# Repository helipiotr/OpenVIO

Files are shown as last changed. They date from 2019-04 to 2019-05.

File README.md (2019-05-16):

# OpenVIO - Open visual-inertial navigation hardware

OpenVIO is an open-source hardware project which aims to allow anyone to collect precisely synchronised visual and inertial data. It has been engineered due to the fact that the existing hardware is either too expensive or hard to get, barring anyone interested in this discipline from accesing the raw data. Despite its simplicity and design quirks, it is theoretically able to achieve accuracy and performance on par with the existing VIO solutions. Contributions and issues are welcome.

# Brief description
The system is composed of the following sub-systems:
- Raspberry Pi (version higher than 3) - collects the visual data via the PiCamera. Also, it generates the frame synchronization pulses [RPi_frame_sync](https://www.raspberrypi.org/forums/viewtopic.php?t=190314) by altering the configuration blob so that the Broadcom SoC pins are connected directly to the header.
- An expansion board featuring a STM32 microcontroller, that also has ADXL355 chip and BMG160 gyroscope. Its purpurse is to collect the inertial data in real time and send it Raspberry Pi in lax timing constraints. Alternatively, it can be used as an INS (inertial navigation system) that receives the pose corrections from the Raspberry Pi.
- A camera connected to the Raspberry Pi

The example software that was written with an intent to capture the raw data is included. It consists of camera sensor data mode on the microcontroller side and a program to read and store binary blobs that are being sent from the microcontroller. They can be analised using e.g. octave, python, or any other preferred language, but must be parsed to keep the data types first. Main features:
- Reading sensors in specified interval
- Possible synchronization of the sensor reading times with the image capture intervals
- Versatile sensor configuration
- High performance ADXL355 acceleration sensor (drivers ready)
- BMG160 gyroscope (drivers ready)
- DPS310 barometer
- BMA150 magnetometer

# Getting the hardware
It is possible to either use the attached Altium Designer files or use the generated Gerber files, depending on the preference. If some of the BOM are not easily accessible, please report this in issues and I'll consider replacing the component. Even better, consider contributing to the repository. 

# Programming and development
Before any programming, it is required to re-configure the pinout of the Raspberry Pi as described in [RPi_frame_sync](https://www.raspberrypi.org/forums/viewtopic.php?t=190314). Only after that RPi can be used with the sensor expansion board. GPU memory increase for the camera might be required for capturing the full sensor resolution, this can be done by changing a line in a configuration file.

Regarding the software embedded in STM32, AC6 development software is preffered to be used with the existing project. The microcontroller can be programmed using any STM32F4 compatible programmer. 

# Known issues
- The time synchronization is a bit off, this should be like 1ms but is actually closer to 0.991ms. Likely a timer issue.
- The DMA that is being used for the communication between Raspberry Pi and STM32 is failing quite routinely. Maybe a change in protocol / communication paradigm (DMA timeouts?) will bring this to an end.
- As DMA quite routinely fails, this messes up the timing data completely. Please don't be surprised if the saved binary blob contains nonsense, very often acceleration / angular velocity data is just fine with timing being just garbage.
- Gyroscope in hardware version 1.2 is not yet supported, but the library can be easily added from the Bosch Sensortronic website. 

# License
All hardware must not be used for any activity other than academic or educational due to the licensing. Software that contains a copyright notice from Bosch Sensortec GmbH has to be distributed within the limits of this license. All other components are subject to the MIT license.

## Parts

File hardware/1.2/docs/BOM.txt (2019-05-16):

Comment	Description	Designator	Footprint	LibRef	Quantity

"Cap Semi"	"Capacitor (Semiconductor SIM Model)"	"C1, C6, C8, C10, C12, C13, C14, C17, C18, C19, C20, C21, C22, C23, C24, C25, C26, C27, C28, C29, C30"	"C1206"	"Cap Semi"	"21"
"Cap Semi"	"Capacitor (Semiconductor SIM Model)"	"C2, C4, C5, C7, C9, C11, C15, C16, C31, C32, C33"	"C1210"	"Cap Semi"	"11"
"LED3"	"Typical BLUE SiC LED"	"D1, D2, D3"	"3.5X2.8X1.9"	"LED3"	"3"
"D Schottky"	"Schottky Diode"	"D4"	"SMB"	"D Schottky"	"1"
"BMG250"	""	"MEMS1"	"LGA14-BOSCH"	"BMG250"	"1"
"ADXL355BEZ"	"Imported"	"MEMS2"	"E_14_1"	"ADXL355BEZ"	"1"
"BMA150"	""	"MEMS3"	"BGA12-BOSCH"	"BMA150"	"1"
"DPS310"	""	"MEMS4"	"PG-VLGA-8-1"	"DPS310"	"1"
"Header 20X2"	"Header, 20-Pin, Dual row"	"P1"	"HDR2X20"	"Header 20X2"	"1"
"Header 6"	"Header, 6-Pin"	"P2"	"HDR1X6"	"Header 6"	"1"
"SYNC_SEL"	"Header, 3-Pin"	"P3"	"HDR1X3"	"Header 3"	"1"
"EN_SRC_SEL"	"Header, 3-Pin"	"P4"	"HDR1X3"	"Header 3"	"1"
"UC_PWR_SEL"	"Header, 3-Pin"	"P5"	"HDR1X3"	"Header 3"	"1"
"Res3"	"Resistor"	"R1, R2, R3, R4, R5, R6, R7, R8, R9, R10, R11, R12, R13"	"J1-0603"	"Res3"	"13"
"SW-DPST"	"Double-Pole, Single-Throw Switch"	"S1"	"TACT_SWITCH"	"SW-DPST"	"1"
"STM32F4x1R1"	"Imported"	"U2"	"LQFP64-10x10mm"	"STM32F4x1R1"	"1"
"MCP1825"	"3.3V Voltage regulator"	"VR1, VR2"	"SOT-223-6"	"MCP1825"	"2"
"LFXTAL026380"	""	"Y1"	"12SMX-B"	"LFXTAL026380"	"1"

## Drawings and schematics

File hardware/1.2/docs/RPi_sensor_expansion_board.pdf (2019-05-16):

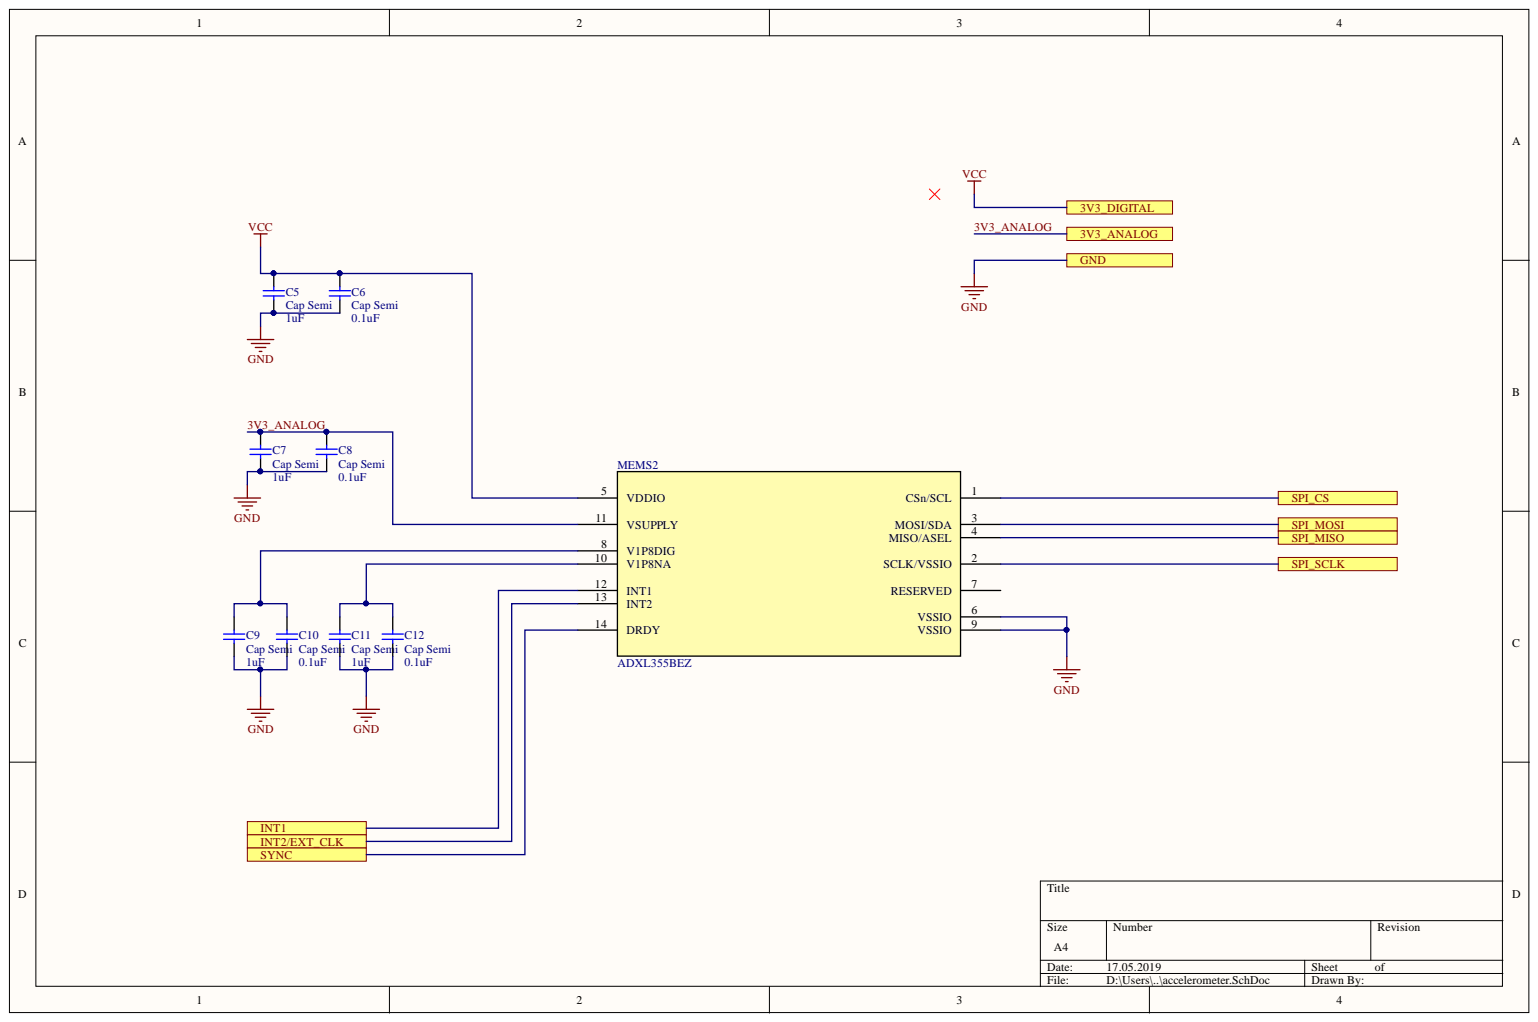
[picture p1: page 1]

INT1 12
INT2 13

DRDY 14

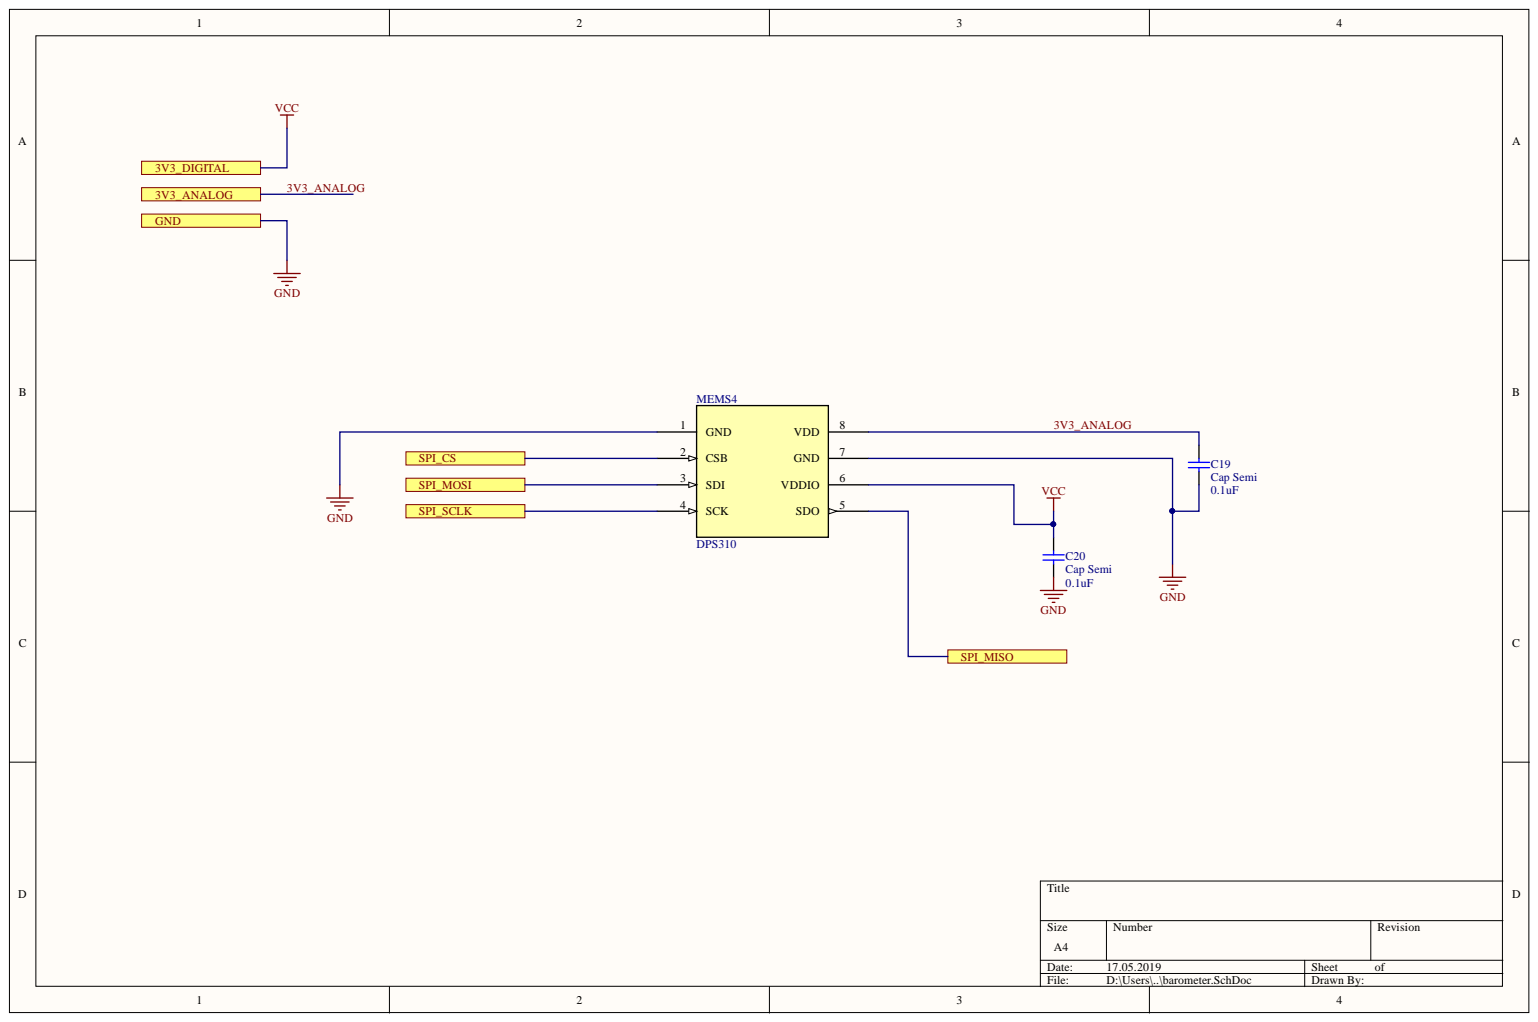
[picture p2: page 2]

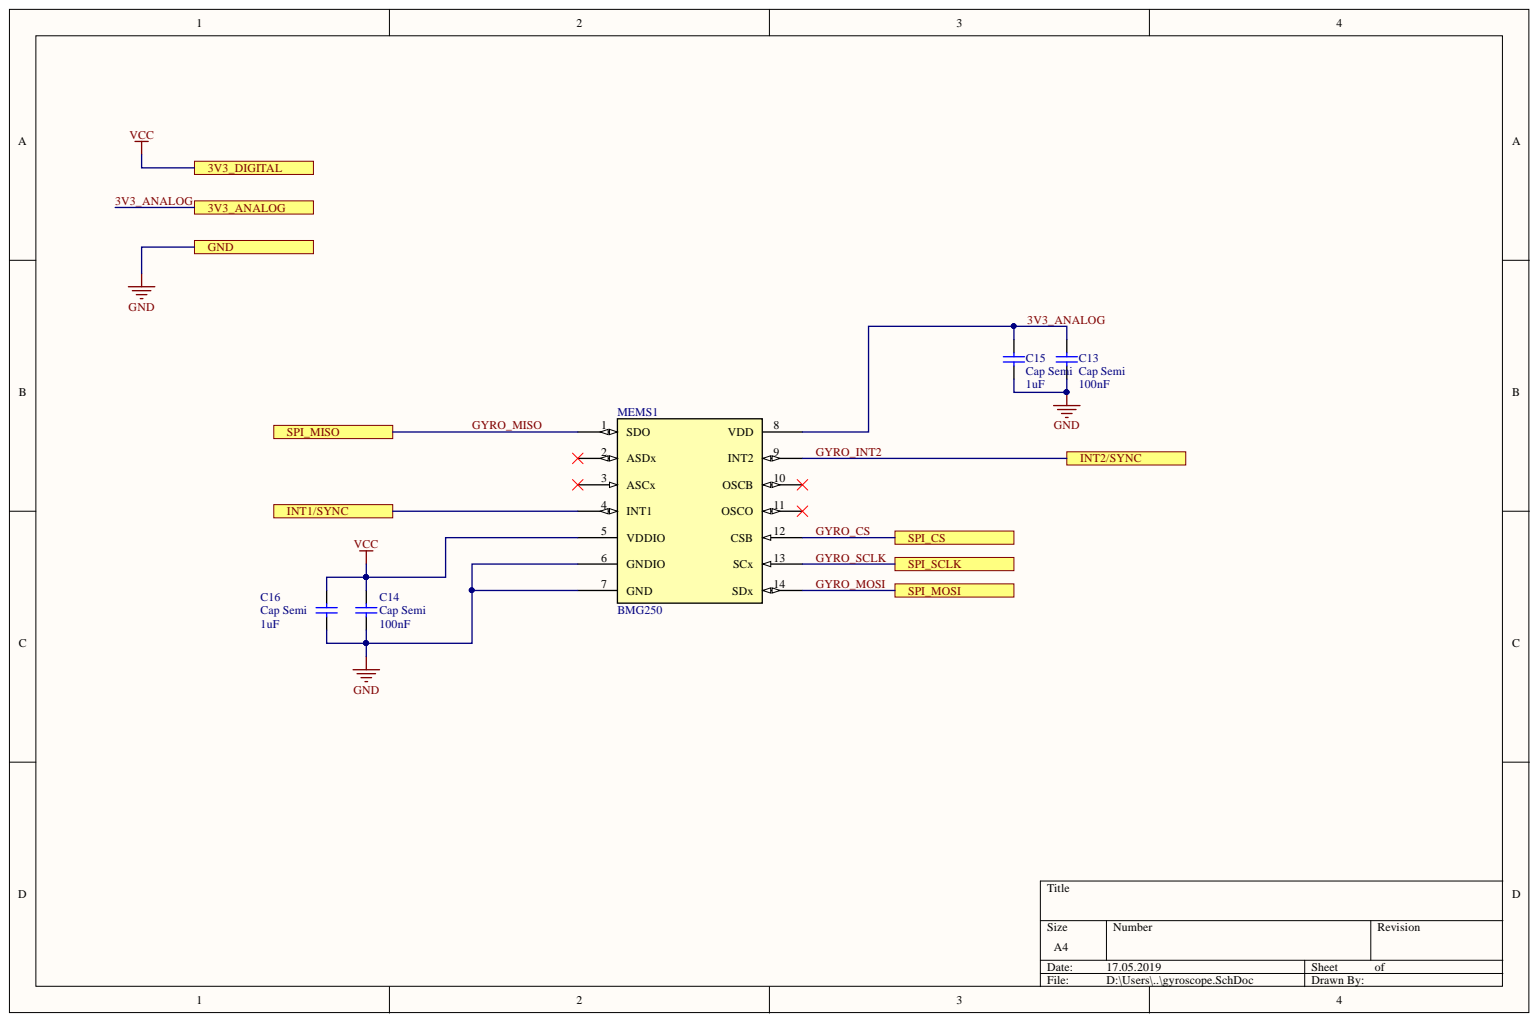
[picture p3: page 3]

GNDIO 6

GND 7

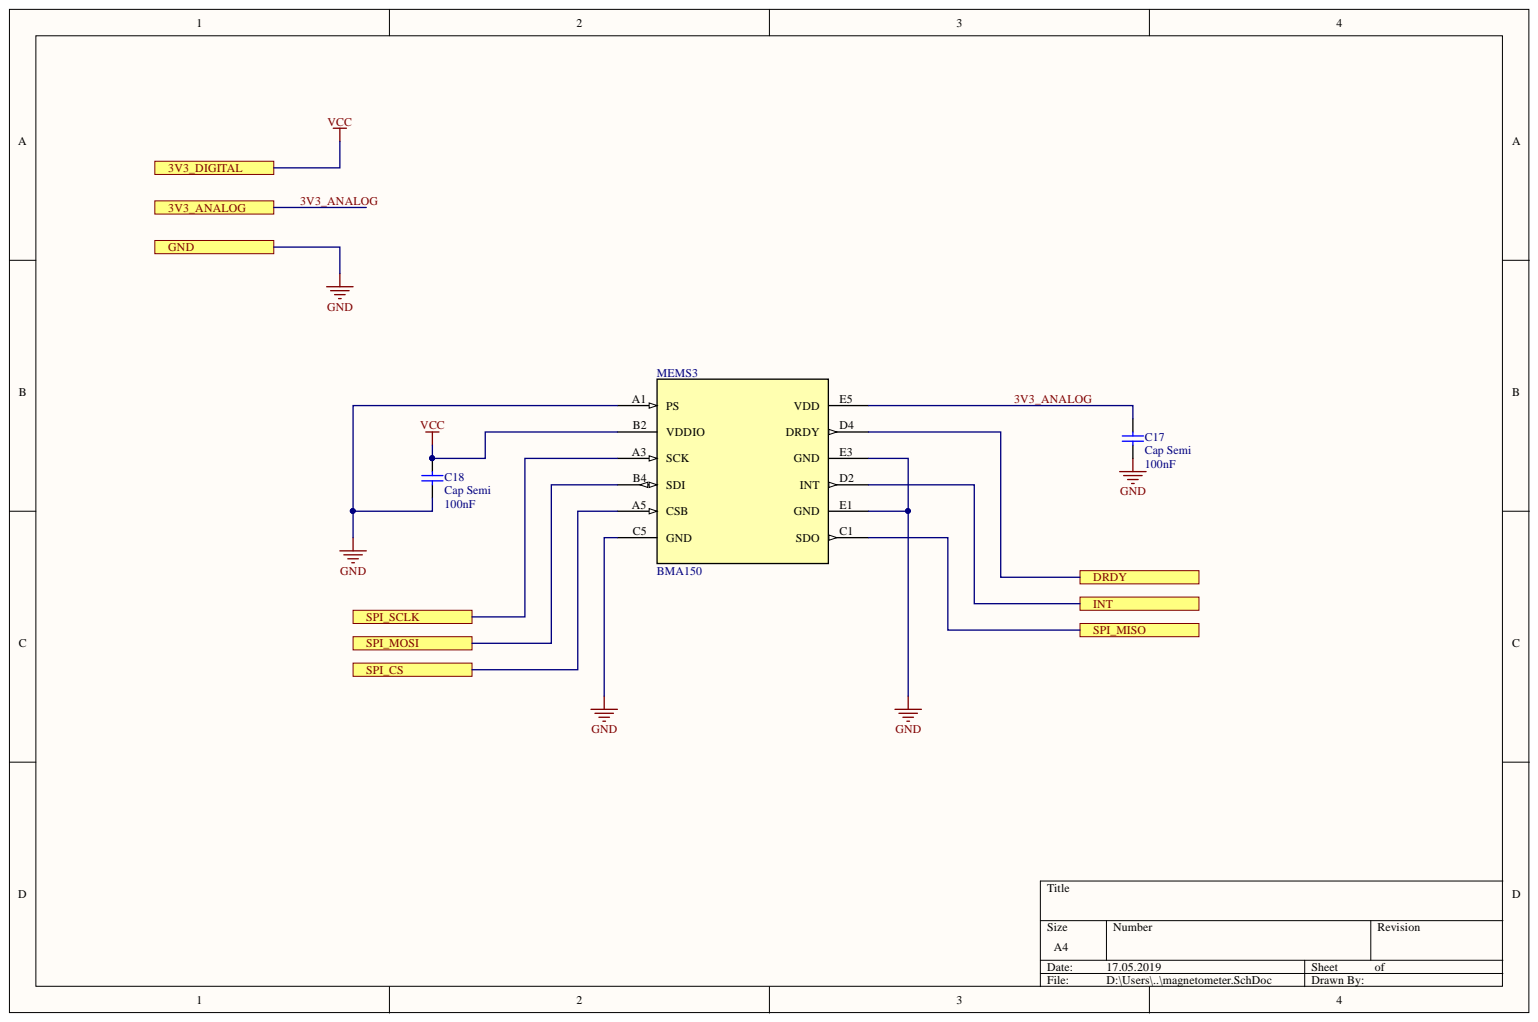
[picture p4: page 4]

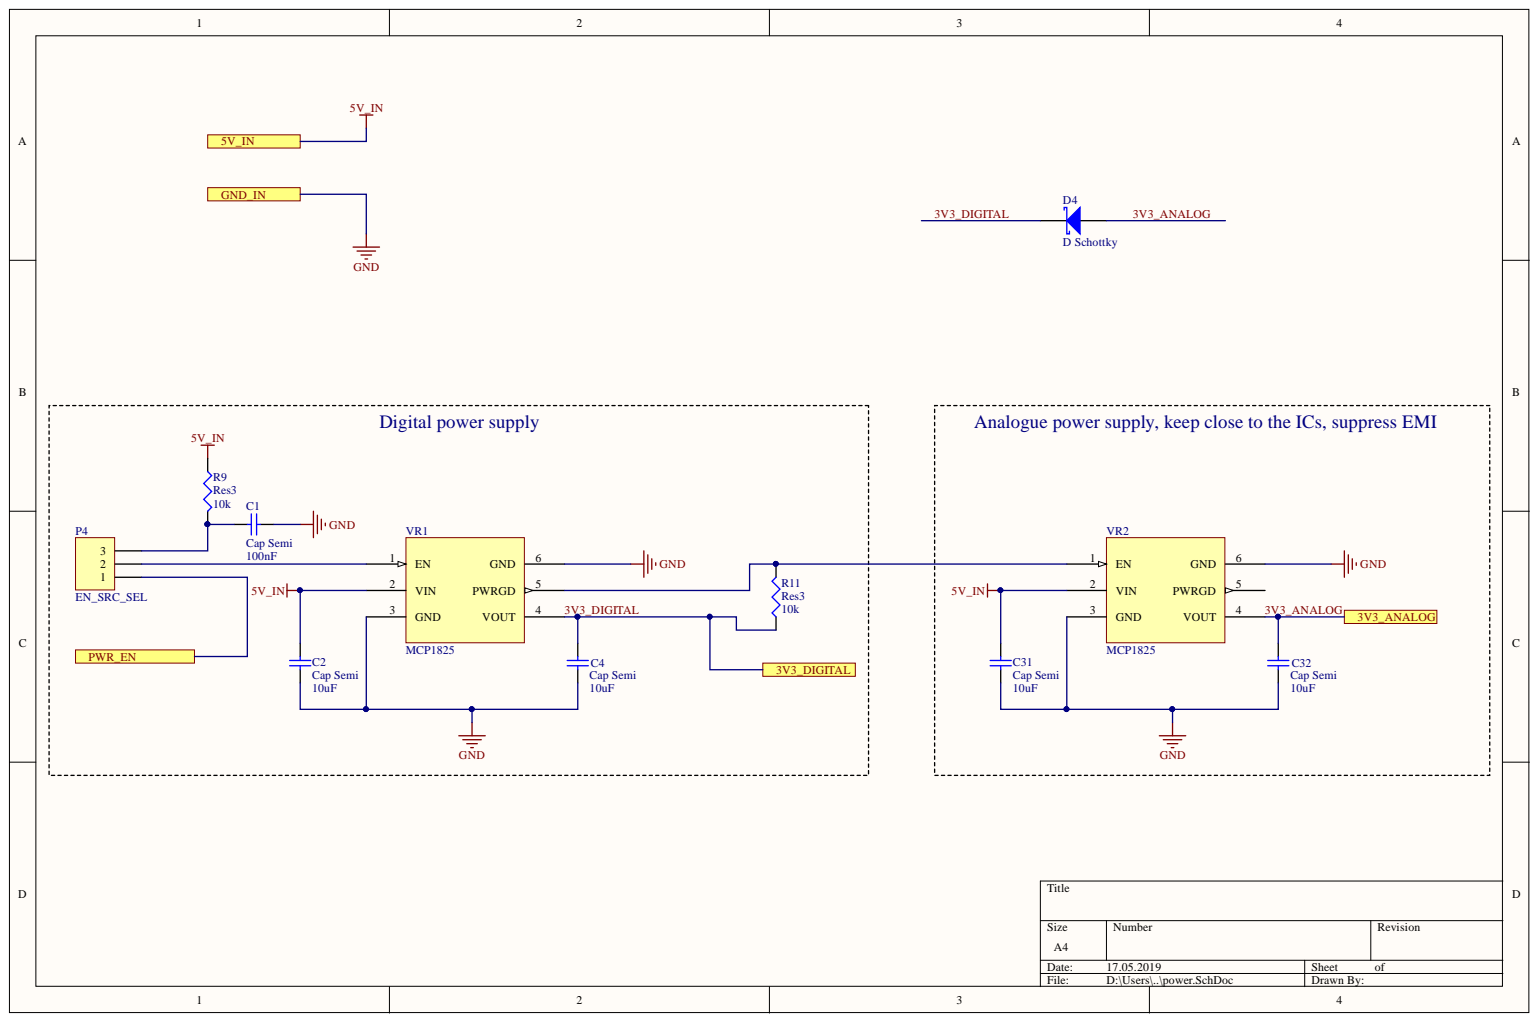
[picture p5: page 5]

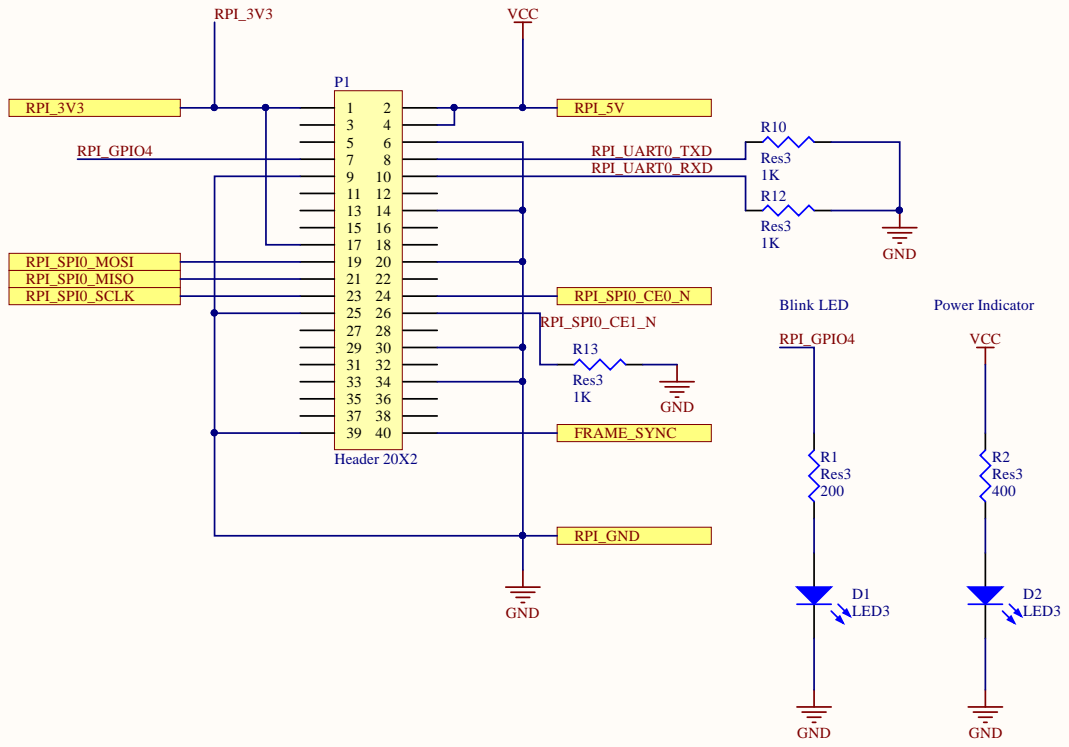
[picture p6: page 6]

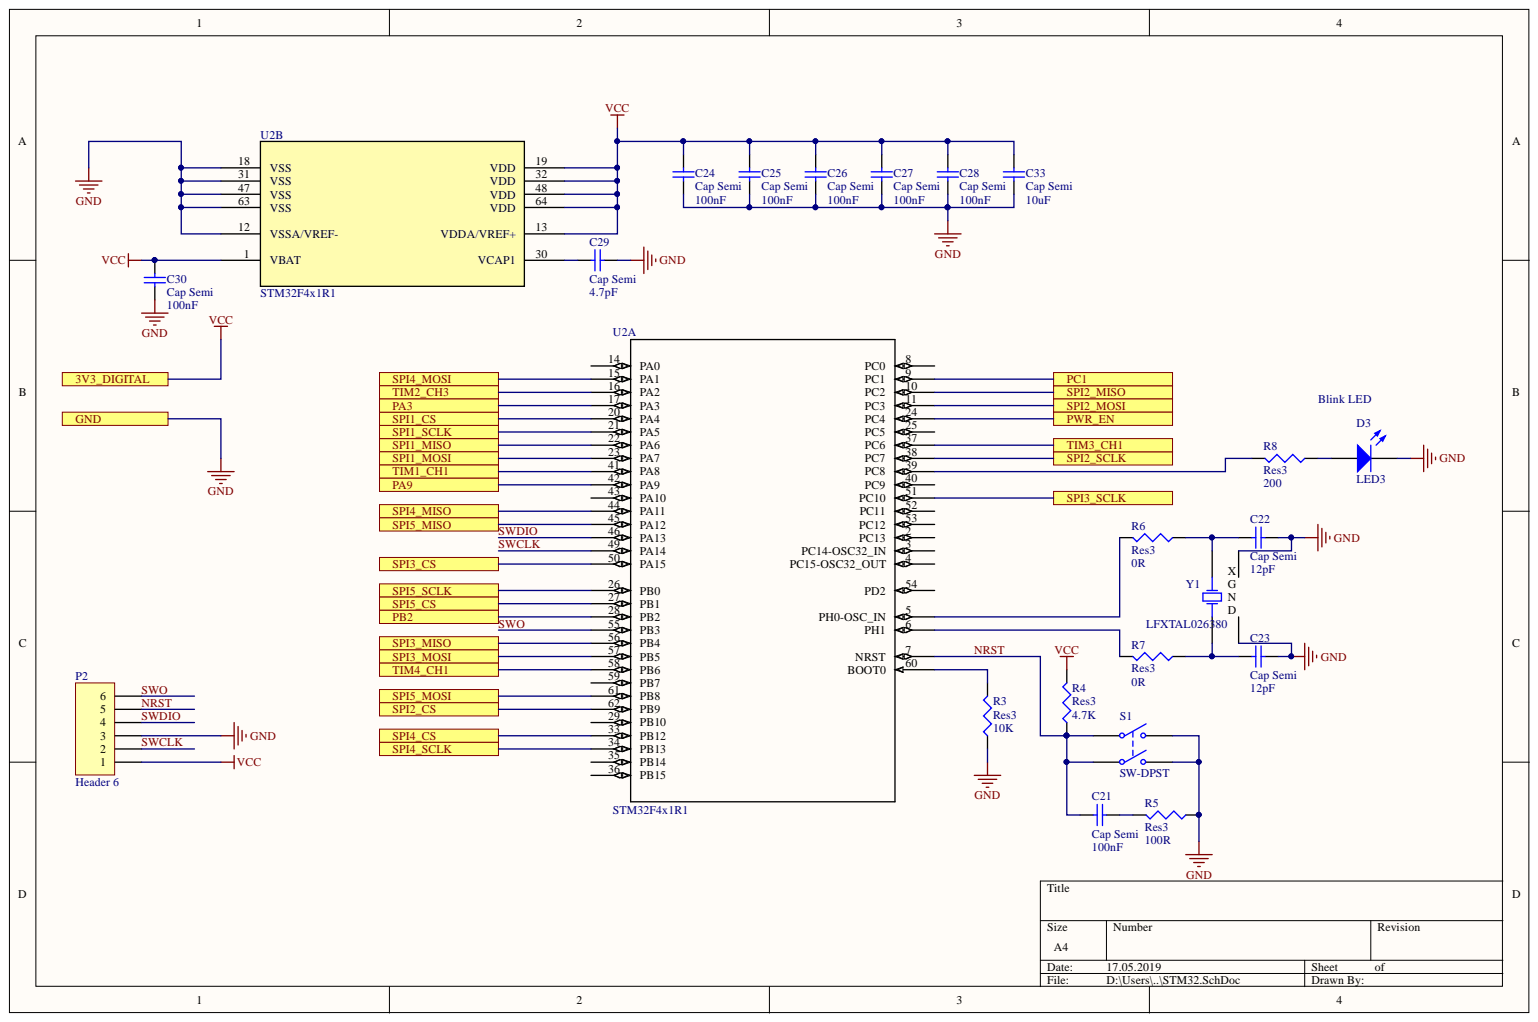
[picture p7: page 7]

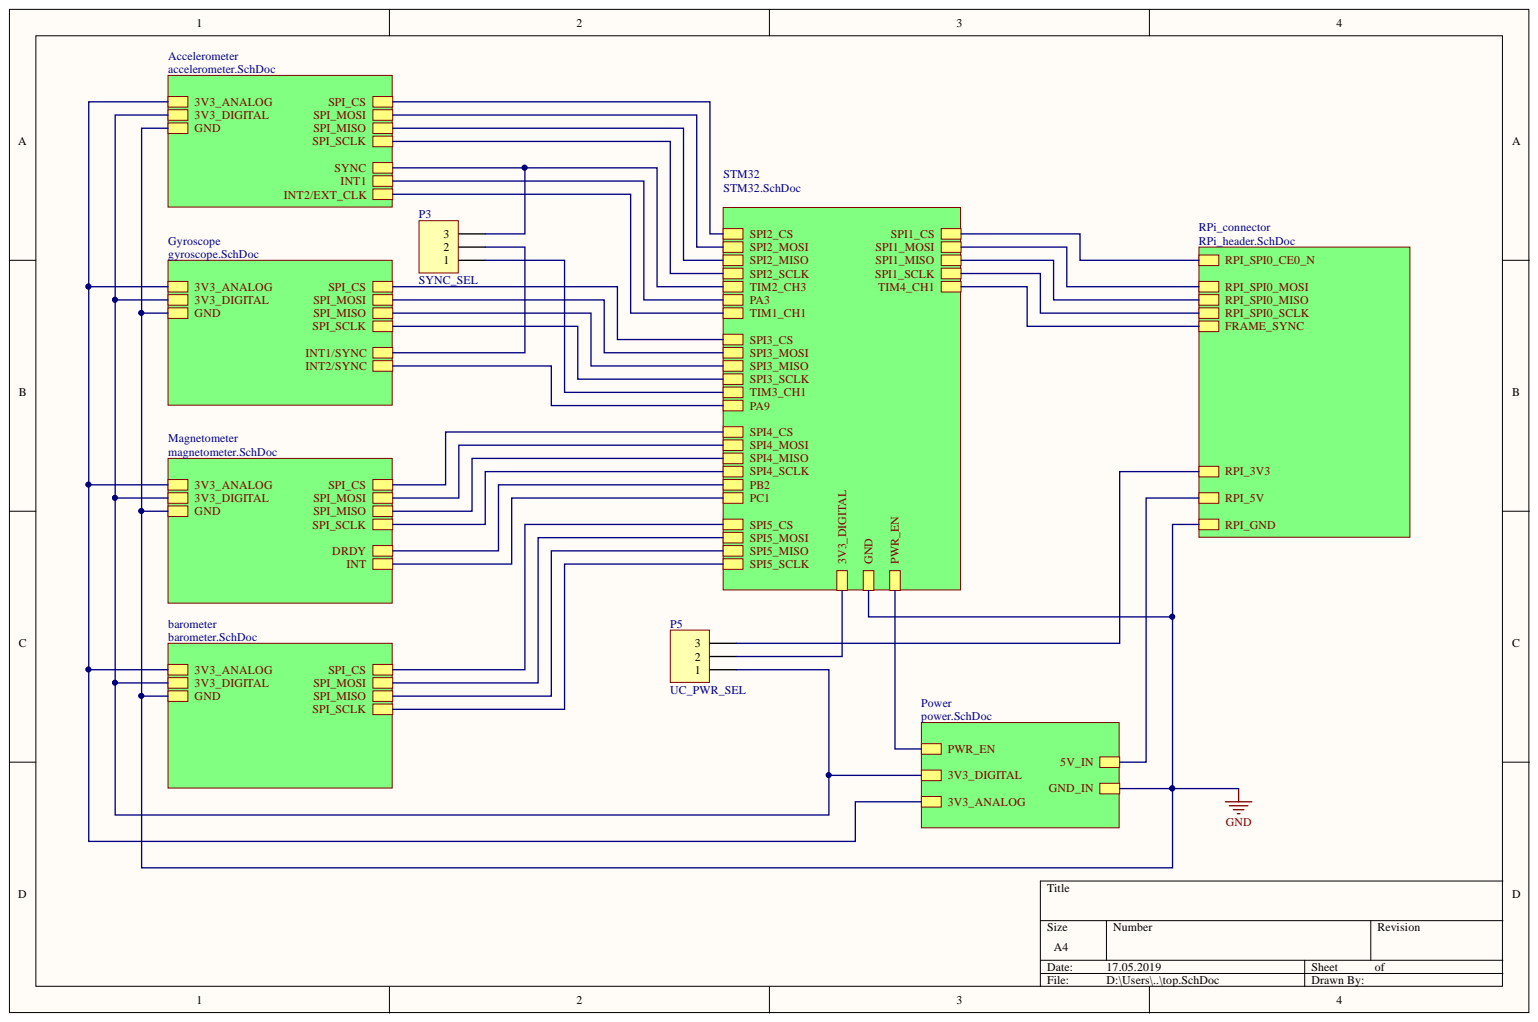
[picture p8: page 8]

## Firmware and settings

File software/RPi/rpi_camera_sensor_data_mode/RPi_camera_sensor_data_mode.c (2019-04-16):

#include <stdint.h>
#include <unistd.h>
#include <stdio.h>
#include <stdlib.h>
#include <getopt.h>
#include <fcntl.h>
#include <sys/ioctl.h>
#include <linux/types.h>
#include <linux/spi/spidev.h>

#include "RPi_camera_sensor_data_mode.h"

//hardcoded for the time being, can be modified with an optarg
static const char *device = "/dev/spidev0.0";
	
static uint8_t bits = 8; //maximum number allowed by the driver
static uint32_t speed = 100000;
static uint32_t spi_max_words = 1024;

//a default value of 10 seconds
static unsigned int record_time = 10;
static unsigned int default_delay_us = 300;

int main(int argc, char * argv[])
{	
	parse_opts(argc, argv);
	
	//int bmg_range_dummy = BMG160_RANGE_250;
	//printf("BMG160_RANGE_250 value is: %d \n", bmg_range_dummy);
	
	int fd;
	fd = open(device, O_RDWR);
	set_spi(fd);
	uint8_t tx = CAMERA_SENSOR_DATA_MODE;
	
	//set the operating mode to sensor data mode
	
	uint8_t rx = send_receive_single( 
		fd, tx, default_delay_us);
		
	if (rx == COMM_ERROR)
		pabort("Can't set peripheral board operation mode");
	
	//select the sensors
	uint8_t sensor_selection = GYRO_MASK | ACCEL_MASK | CAM_MASK;
	tx = sensor_selection;  
	rx = send_receive_single(fd, tx, default_delay_us);
	if (rx == COMM_ERROR)
		pabort("Wrong sensor selection");
	
	//set up the gyro 
	if (sensor_selection & GYRO_MASK){
		//set range -> lowest as we deal with indoor navigation
		tx = BMG160_RANGE_125;
		rx = send_receive_single(fd, tx, default_delay_us);
		if (rx == COMM_ERROR)
			pabort("Gyro range selection error");
		
		//set bandwidth -> around capture value, 100 Hertz
		tx = BMG160_BW_116_HZ;
		rx = send_receive_single(fd, tx, default_delay_us);
		if (rx == COMM_ERROR)
			pabort("Gyro bandwidth selection error");
		
		printf("Gyro has been configured \n");
	}
	
	//set up the accelerometer
	
	if(sensor_selection & ACCEL_MASK)
	{
		//set accelerometer range
		tx = RANGE_2G;
		rx = send_receive_single(fd, tx, default_delay_us);
		if (rx == COMM_ERROR)
			pabort("Accelerometer range selection error");
		
		//set output data rate
		tx = FILTER_ODR_500;
		rx = send_receive_single(fd, tx, default_delay_us);
		if (rx == COMM_ERROR)
			pabort("Accelerometer ODR selection error");
		
		printf("Accelerometer has been configured \n");
	
	}
	
	//the camera sensor requires no configuration in this release
	
	//confirm the setup
	tx = 0;
	rx = send_receive_single(fd, tx, default_delay_us);
	if (rx != PARAMETERS_SET)
		pabort("Sensor configuration error");
	
	printf("The board has been succesfully configured!\n");
	
	//start the timers
	tx = START_ACQUISITION;
	rx = send_receive_single(fd, tx, default_delay_us); //TODO change delay
	if (rx != COMM_ACKNOWLEDGE)
		pabort("Timers can't have been set");
	
	printf("Timers and the measurement started\n");
	
	//wait for some time to gather data
	//usleep(10000);
	//usleep(10000000);
	
	//sleep period 100ms
	uint32_t sleep_period = 30000;
	usleep(sleep_period);
	
	//receive data length, receive the stored data
	
	uint8_t rx2[2];
	
	uint8_t * rx_ptr;
	uint8_t * tx_ptr;
	FILE * write_ptr;
	
	write_ptr = fopen("measurements.bin","wb");
	
	if(write_ptr == NULL)
	{
		pabort("can't open a file to write");
	}
	
	//Perform multiple data transfers with a delay
	for (int i = 0; i < (record_time*1000000/sleep_period); ++i){
		
		//request the data transfer
		tx = SEND_DATA;
		rx = send_receive_single(fd, tx, default_delay_us); 
		//printf("rx: %d \n", rx);
		if (rx != COMM_ACKNOWLEDGE)
			pabort("Wrong acknowledge to send the data \n ");
		
		//see if we do not have an overflow of the FIFO
		tx = 0;
		rx = send_receive_single(fd, tx, default_delay_us);
		if (rx != COMM_ACKNOWLEDGE)
			pabort("Error, likely a FIFO overflow");
		
		tx = 0;
		rx2[0] = send_receive_single(fd, tx, default_delay_us);
		rx2[1] = send_receive_single(fd, tx, default_delay_us);
		
		uint16_t transfer_size_words = (rx2[1] << 8 ) | rx2[0];
		
		//TODO create multiple transfers in case the there is too much data
		
		//printf("The transfer size (number of u32) is %d \n",  transfer_size_words);
		
		if(transfer_size_words > 0){

			//read the records
			rx_ptr = malloc(sizeof(uint32_t) * transfer_size_words);
			
			//just to prevent segfault, doesn't really matter 
			tx_ptr = malloc(sizeof(uint32_t) * transfer_size_words);
			
			//wait for some time for the microcontroller DMA to prepare
			
			//usleep(sleep_period);
			
			//transfer part-by-part
			uint32_t transfer_mult = transfer_size_words / spi_max_words;
			uint32_t transfer_rem = transfer_size_words % spi_max_words;
			
			//send blocks of max-size
			for (int i = 0 ; i < transfer_mult; ++i){
			
				struct spi_ioc_transfer tr = {
					.tx_buf = (unsigned long) (tx_ptr + i*spi_max_words),
					.rx_buf = (unsigned long) rx_ptr,
					.len = (sizeof(uint32_t) * spi_max_words), //nb of bytes
					.delay_usecs = default_delay_us,
					.speed_hz = 10000000,
					.bits_per_word = bits,
				};
				
				//printf("Starting fast data transfer \n");
				int ret = ioctl(fd, SPI_IOC_MESSAGE(1), &tr);
				if (ret < 1)
					pabort("can't send spi message");
			
			}
			
			struct spi_ioc_transfer tr = {
				.tx_buf = (unsigned long) (tx_ptr + transfer_mult * spi_max_words),
				.rx_buf = (unsigned long) rx_ptr,
				.len = (sizeof(uint32_t) * transfer_rem), //nb of bytes
				.delay_usecs = default_delay_us,
				.speed_hz = 10000000,
				.bits_per_word = bits,
			};
			
			//printf("Starting fast data transfer \n");
			int ret = ioctl(fd, SPI_IOC_MESSAGE(1), &tr);
			if (ret < 1)
				pabort("can't send spi message");
			
			fwrite(rx_ptr,sizeof(uint32_t), transfer_size_words, write_ptr);
			free(tx_ptr);
			free(rx_ptr);
				

			
			//confirm the transfer
			tx = COMM_ACKNOWLEDGE;
			rx = send_receive_single(fd, tx, default_delay_us); //TODO change delay
			if (rx != COMM_ACKNOWLEDGE){

				printf("Transfer confirmation message invalid: %02X, ignored \n", rx);
				//the DMA on the microcontroller sometimes "shifts" by one byte and needs to be pushed forward
				//no idea why this happens, might be something hardware-related. It however is certain that
				//this workaround (sending additional byte) does not corrupt the data (the number of bytes written to
				//the file is correct, so is the actual data).
				tx = COMM_ACKNOWLEDGE;
				rx = send_receive_single(fd, tx, default_delay_us); //TODO change delay
			}
			
			
		} else {
			printf("Transfer size is zero, no bytes transmitted. \n");
			//usleep(5*sleep_period);
		}
		
		usleep(sleep_period);
	}
	


	
	// Stop the acquisition 
	
	tx = STOP_ACQUISITION;
	rx = send_receive_single(fd, tx, default_delay_us);
	if (rx != COMM_ACKNOWLEDGE)
		pabort("Can't stop acquisistion");
	
	printf("Acquisistion stopped \n");
	
	fclose(write_ptr);
	close(fd);
	
	return 0;
}

void pabort(const char *s)
{
	perror(s);
	abort();
}

//void send_receive_multiple(int fd, uint8_t * tx, uint8_t * rx,
//		uint16_t records_number,  uint16_t delay)

uint8_t send_receive_single(int fd, uint8_t tx, uint16_t delay)
{
	uint8_t rx;
	int ret;
	struct spi_ioc_transfer tr = {
		.tx_buf = (unsigned long) &tx,
		.rx_buf = (unsigned long) &rx,
		.len = 1, //just one byte
		.delay_usecs = delay,
		.speed_hz = speed,
		.bits_per_word = bits,
	};
	
	ret = ioctl(fd, SPI_IOC_MESSAGE(1), &tr);
	if (ret < 1)
		pabort("can't send spi message");
	
	return rx;
}

void parse_opts(int argc, char * argv[])
{
	while (1)
	{
		static const struct option lopts[] = {
			{"record_time", 1, 0, 't'},
			{NULL, 0, 0, 0},
			//does effectively nothing but does
			//a splendid job not allowing for a segfault				
		};
		
		int c;
		
		c = getopt_long(argc, argv, "t:", lopts, NULL);
		
		//only way to exit this loop
		if ( c == -1)
			break;
		
		switch (c) {
			case 't':
				record_time = atoi(optarg);
				printf("Set operation time %d seconds \n",record_time);
				break;
			default:
				print_usage();
				break;
		}
	}
}

void print_usage(void)
{
	printf("Usage: [-t]");
	puts("-t --record_time \t time of required operation");
	
	exit(1);
}

void set_spi(int fd)
{
	// set the SPI operating mode
	
	int ret = 0;
	uint8_t mode = 0; //can be ORed in the future
	
	ret = ioctl(fd, SPI_IOC_WR_MODE, &mode);
	if (ret == -1)
		pabort("can't set spi mode");
	
	ret = ioctl(fd, SPI_IOC_RD_MODE, &mode);
	if (ret == -1)
		pabort("can't get spi mode");
	
	// set the number of bits to be transferred

	
	ret = ioctl(fd, SPI_IOC_WR_BITS_PER_WORD, &bits);
	if (ret == -1)
		pabort("can't set bits per word");

	ret = ioctl(fd, SPI_IOC_RD_BITS_PER_WORD, &bits);
	if (ret == -1)
		pabort("can't get bits per word");
	
	//set the speed of the SPI
	
	ret = ioctl(fd, SPI_IOC_WR_MAX_SPEED_HZ, &speed);
	if (ret == -1)
		pabort("can't set max speed hz");

	ret = ioctl(fd, SPI_IOC_RD_MAX_SPEED_HZ, &speed);
	if (ret == -1)
		pabort("can't get max speed hz");
	
	
	//print the information about the SPI configuration
	printf("Spi mode: %d\n", mode);
	printf("Bits per word: %d\n", bits);
	printf("Max speed: %d Hz (%d KHz)\n", speed, speed/1000);
	
}

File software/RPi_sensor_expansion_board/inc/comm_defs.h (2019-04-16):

/*  \Name: comm_defs.h
 *  \Brief: Definitions of values used in the communication implementation
 *  \Note: This lists values shared with the main unit that allow the communication
 */

#ifndef COMM_DEFS_H_
#define COMM_DEFS_H_


// Possible operating modes
#define SENSOR_DATA_MODE			(0)
#define CAMERA_SENSOR_DATA_MODE		(1)
#define NAVIGATION_MODE				(2)

// Communication codes
#define COMM_ERROR 					(0)
#define COMM_ACKNOWLEDGE			(1)
#define PARAMETERS_SET				(2)
#define START_ACQUISITION			(3)
#define STOP_ACQUISITION			(4)
#define SEND_DATA					(5)

// Bit masks of the sensors
#define GYRO_MASK					(1)
#define ACCEL_MASK					(1<<1)
#define MAG_MASK					(1<<2)
#define BAR_MASK					(1<<3)
#define CAM_MASK					(1<<4)

//Capture rate definitions
#define CAPTURE_RATE_100HZ			(10)
#define CAPTURE_RATE_200HZ			(5)
#define CAPTURE_RATE_500HZ			(2)
#define CAPTURE_RATE_1000HZ			(1)


// Copy some of the definitions for the use of the main unit
#ifndef __BMG160_H__
/***********************************************/
/**\name	RANGE DEFINITIONS*/
/**********************************************/
#define BMG160_RANGE_2000	(0x00)
#define BMG160_RANGE_1000	(0x01)
#define BMG160_RANGE_500	(0x02)
#define BMG160_RANGE_250	(0x03)
#define BMG160_RANGE_125	(0x04)

/***********************************************/
/**\name	BANDWIDTH DEFINITIONS*/
/**********************************************/
#define C_BMG160_NO_FILTER_U8X			(0)
#define	C_BMG160_BW_230HZ_U8X			(1)
#define	C_BMG160_BW_116HZ_U8X			(2)
#define	C_BMG160_BW_47HZ_U8X			(3)
#define	C_BMG160_BW_23HZ_U8X			(4)
#define	C_BMG160_BW_12HZ_U8X			(5)
#define	C_BMG160_BW_64HZ_U8X			(6)
#define	C_BMG160_BW_32HZ_U8X			(7)

#define BMG160_BW_500_HZ	(0x01)
#define BMG160_BW_230_HZ	(0x01)
#define BMG160_BW_116_HZ	(0x02)
#define BMG160_BW_47_HZ		(0x03)
#define BMG160_BW_23_HZ		(0x04)
#define BMG160_BW_12_HZ		(0x05)
#define BMG160_BW_64_HZ		(0x06)
#define BMG160_BW_32_HZ		(0x07)


#endif /* __BMG160_H__ */

// Copy some of the definitions for the use of the main unit
#ifndef ADXL355_H_

/***********************************************/
/**\name	BANDWIDTH DEFINITIONS*/
/**********************************************/

#define FILTER_ODR_4000 		 (0x00)
#define FILTER_ODR_2000			 (0x01)
#define FILTER_ODR_1000 		 (0x02)
#define FILTER_ODR_500  		 (0x03)
#define FILTER_ODR_250			 (0x04)
#define FILTER_ODR_125			 (0x05)
#define FILTER_ODR_62 			 (0x06)
#define FILTER_ODR_32			 (0x07)
#define FILTER_ODR_16			 (0x08)
#define FILTER_ODR_8			 (0x09)
#define FILTER_ODR_4			 (0x0A)


/***********************************************/
/**\name	RANGE DEFINITIONS*/
/**********************************************/

#define RANGE_2G				 (0x01)
#define RANGE_4G				 (0x02)
#define RANGE_8G				 (0x03)



#endif /* ADXL355_H_ */






#endif /* COMM_DEFS_H_ */

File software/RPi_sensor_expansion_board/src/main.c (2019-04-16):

/**
  ******************************************************************************
  * @file    main.c
  * @author  Ac6
  * @version V1.0
  * @date    01-December-2013
  * @brief   Default main function.
  ******************************************************************************
*/


#include "stm32f4xx.h"
#include "system.h"
#include "gyro.h"
#include "accel.h"
#include "cam.h"
#include "comm.h"
#include "modes/sensor_data_mode.h"
#include "modes/camera_sensor_data_mode.h"

void NVIC_Conf(void){
	//Setting global priority group
	NVIC_PriorityGroupConfig(NVIC_PriorityGroup_0 );
}


int main(void)
{

	//setting the main quartz oscillator and PLL
	RCC_Conf();

	NVIC_Conf(); // NVIC requires clocked peripherals

	gyro_setup();
	accel_setup();
	cam_setup();
	comm_setup();

	GPIO_InitTypeDef portC;

	portC.GPIO_Pin = GPIO_Pin_8;
	portC.GPIO_Mode = GPIO_Mode_OUT;
	portC.GPIO_OType = GPIO_OType_PP;
	portC.GPIO_PuPd = GPIO_PuPd_NOPULL;
	portC.GPIO_Speed = GPIO_Speed_50MHz;
	GPIO_Init(GPIOC, &portC);

	//main loop waiting and redirecting to the proper communication mode
	while(1){

		u8 required_mode = comm_get_mode();
		s8 operation_result = 0;

		 switch (required_mode) {
		   case SENSOR_DATA_MODE:
			   GPIO_SetBits(GPIOC, GPIO_Pin_8);
			   //sensor_data_mode_set_parameters();
			   operation_result = sensor_data_mode_main();
			   //insert code here
		     break;
		   case CAMERA_SENSOR_DATA_MODE:
			   GPIO_SetBits(GPIOC, GPIO_Pin_8);
			   operation_result = camera_sensor_data_mode_main();
			   //to be used after a proper module is written
		     break;
		   default:
			   GPIO_ResetBits(GPIOC, GPIO_Pin_8);
			   comm_send_error();
		     break;
		 }
		/*GPIO_SetBits(GPIOC, GPIO_Pin_8);
		BMG160_delay_msek(500);
		GPIO_ResetBits(GPIOC, GPIO_Pin_8);
		BMG160_delay_msek(500);*/
	}
}

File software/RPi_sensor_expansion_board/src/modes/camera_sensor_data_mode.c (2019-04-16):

/*
 * camera_camera_sensor_data_mode.c
 *
 *  Created on: 07.02.2019
 *      Author: helipiotr
 */


/*
 * \Name camera_sensor_data_mode.c
 */

#include "modes/camera_sensor_data_mode.h"
#include "stm32f4xx_dma.h" //reinclude?
#include "stm32f4xx_spi.h"

//failure / success definitions
static const s8 CAMERA_SENSOR_DATA_MODE_SUCCESS = 0;
static const s8 CAMERA_SENSOR_DATA_MODE_ERROR = -1;

/*!
 * \Brief: data structure holding the data for the main unit
 *
 * This array holds various values that may be represented as
 * signed or unsigned values: needs to be taken care of. Alignment:
 * \Note: - (u32) sensor type, refer to bit masks in comm_defs.h
 * \Note: - (u32) timestamp in microseconds
 * \Note: - (s32) x data (sensor) or (u32) frame_begin->1,
 * 			frame_end -> 0
 * \Note: - (s32) y data (sensor) or (u32) frame number
 * \Note: - (s32) z data (sensor) or empty
 */
static u32 volatile sensor_readings[CAMERA_SENSOR_DATA_MODE_RECORDS_CAPACITY]
						   [CAMERA_SENSOR_DATA_MODE_RECORDS_WIDTH];

static int volatile FIFO_in = 0; //shows an empty place for the next record
static int volatile FIFO_out = 0; //current location of the output
static int volatile FIFO_err = 0; //to be checked before the transmission
static int volatile tx_complete = 0;

static int strobe = 0; //TODO remove after tests

//decimate to achieve a certain capture frequency, e.g. 200Hz
static int volatile capture_rate_decimation = 1;

struct active_sens_str active_sensors = {0, 0, 0};

s8 camera_sensor_data_mode_main(void){

	shared_lock( CAMERA_SENSOR_DATA_MODE_MUTVAL );

	//start with setting the parameters of the transmission
	if (camera_sensor_data_mode_set_parameters() == CAMERA_SENSOR_DATA_MODE_ERROR){
		comm_send_error();
		return CAMERA_SENSOR_DATA_MODE_ERROR;
	}

	//configure TIM5 to timestamp data and TIM2 to trigger recording
	camera_sensor_data_mode_conf_timer();

	while(SPI_I2S_GetFlagStatus(SPI1, SPI_I2S_FLAG_TXE)==RESET){}
	SPI_I2S_SendData(SPI1,COMM_ACKNOWLEDGE);
	while(SPI_I2S_GetFlagStatus(SPI1, SPI_I2S_FLAG_RXNE)==RESET){}

	if (SPI_I2S_ReceiveData(SPI1) != (u16) START_ACQUISITION){
		comm_send_error();
		return CAMERA_SENSOR_DATA_MODE_ERROR;
	}

	//turn on timers as we are starting the measurement
	TIM_SetCounter(TIM2, 0);
	TIM_SetCounter(TIM5, 0);
	TIM_Cmd(TIM2, ENABLE);
	TIM_Cmd(TIM5, ENABLE);

	s8 comm_result;
	while( 1 ){
		//get requested operation

		while(SPI_I2S_GetFlagStatus(SPI1, SPI_I2S_FLAG_TXE)==RESET){}
		SPI_I2S_SendData(SPI1,COMM_ACKNOWLEDGE);
		while(SPI_I2S_GetFlagStatus(SPI1, SPI_I2S_FLAG_RXNE)==RESET){}

		u16 received_data = SPI_I2S_ReceiveData(SPI1);

		if ( received_data == STOP_ACQUISITION){
			//stop regardless the FIFO status
			camera_sensor_data_mode_shutdown();
			return CAMERA_SENSOR_DATA_MODE_SUCCESS;
		} else if (received_data == SEND_DATA && !FIFO_err) {
			//Send a confirmation
			while(SPI_I2S_GetFlagStatus(SPI1, SPI_I2S_FLAG_TXE)==RESET){}
			SPI_I2S_SendData(SPI1,COMM_ACKNOWLEDGE);
			while(SPI_I2S_GetFlagStatus(SPI1, SPI_I2S_FLAG_RXNE)==RESET){}
			SPI_I2S_ReceiveData(SPI1);

			comm_result = camera_sensor_data_mode_send_readings();
		}else{
			camera_sensor_data_mode_shutdown();
			comm_send_error();
			return CAMERA_SENSOR_DATA_MODE_ERROR;
		}

		//go back in case communication failed
		if(comm_result == CAMERA_SENSOR_DATA_MODE_ERROR){
			camera_sensor_data_mode_shutdown();
			comm_send_error();
			return CAMERA_SENSOR_DATA_MODE_ERROR;
		}

	}

	return CAMERA_SENSOR_DATA_MODE_SUCCESS;
}

void camera_sensor_data_mode_shutdown(void){
	TIM_Cmd(TIM2, DISABLE);
	TIM_Cmd(TIM5, DISABLE);
	FIFO_in = 0;
	FIFO_out = 0;
	FIFO_err = 0;
	EXTI_DeInit();
	shared_free( CAMERA_SENSOR_DATA_MODE_MUTVAL );
}

s8 camera_sensor_data_mode_send_readings(){

	//number of uint32_t to be transferred (in words)
	u16 transfer_size_words;
	int mem_layout_cont;

	//lock the value until the transfer is complete -> really thread-safe?
	int FIFO_in_transfer = FIFO_in;

	//calculate wrap-around value
	int mem_layout_thresh = 0;

	// Compute the size of the FIFO block to transfer
	if( (FIFO_in_transfer - FIFO_out ) >= 0){
		transfer_size_words = (FIFO_in_transfer - FIFO_out) *
				CAMERA_SENSOR_DATA_MODE_RECORDS_WIDTH;
		mem_layout_cont = 1;
	}
	else{
		//Transfer just one block on memory
		transfer_size_words = (CAMERA_SENSOR_DATA_MODE_RECORDS_CAPACITY - FIFO_out)
				* CAMERA_SENSOR_DATA_MODE_RECORDS_WIDTH;
		mem_layout_cont = 0;
		mem_layout_thresh = (CAMERA_SENSOR_DATA_MODE_RECORDS_CAPACITY - FIFO_out)
				*CAMERA_SENSOR_DATA_MODE_RECORDS_WIDTH;
	}

	//send the number of the elements stored in the FIFO
	u8 to_send[2];

	to_send[0] = 0xFF & transfer_size_words; //LSB
	to_send[1] = transfer_size_words >> 8; //MSB

	for (int i = 0; i < 2 ; ++i){
		while(SPI_I2S_GetFlagStatus(SPI1, SPI_I2S_FLAG_TXE)==RESET){}
		SPI_I2S_SendData(SPI1,to_send[i]);
		while(SPI_I2S_GetFlagStatus(SPI1, SPI_I2S_FLAG_RXNE)==RESET){}
		SPI_I2S_ReceiveData(SPI1);
	}

	//return when there is nothing to transfer
	if (transfer_size_words == 0){
		return CAMERA_SENSOR_DATA_MODE_SUCCESS;}

	//Configure the SPI to transmit only

	comm_set_SPI_1Line_Tx();

	//Configure the interrupt

	NVIC_InitTypeDef NVIC_InitStructure;
	NVIC_InitStructure.NVIC_IRQChannel = DMA2_Stream2_IRQn;
	NVIC_InitStructure.NVIC_IRQChannelPreemptionPriority = 0;
	NVIC_InitStructure.NVIC_IRQChannelSubPriority = 3;
	NVIC_InitStructure.NVIC_IRQChannelCmd = ENABLE;
	NVIC_Init(&NVIC_InitStructure);

	//Configure the DMA
	//Turn on the DMA clock
	RCC_AHB1PeriphClockCmd(RCC_AHB1Periph_DMA2, ENABLE);
	DMA_DeInit(DMA2_Stream2);

	DMA_InitTypeDef DMAinit;
	DMAinit.DMA_PeripheralBaseAddr = (u32) &(SPI1->DR);
	DMAinit.DMA_Memory0BaseAddr = (u32) &sensor_readings[FIFO_out][0];
	DMAinit.DMA_DIR = DMA_DIR_MemoryToPeripheral;
	DMAinit.DMA_BufferSize = transfer_size_words * sizeof(u32);
	DMAinit.DMA_PeripheralInc = DMA_PeripheralInc_Disable;
	DMAinit.DMA_PeripheralDataSize = DMA_PeripheralDataSize_Byte;
	DMAinit.DMA_MemoryDataSize = DMA_MemoryDataSize_Byte;
	DMAinit.DMA_MemoryInc = DMA_MemoryInc_Enable;
	DMAinit.DMA_Mode = DMA_Mode_Normal;
	DMAinit.DMA_Priority = DMA_Priority_VeryHigh;
	DMAinit.DMA_Channel = DMA_Channel_2;
	DMAinit.DMA_PeripheralBurst = DMA_PeripheralBurst_Single;
	DMAinit.DMA_MemoryBurst = DMA_MemoryBurst_Single;
	DMAinit.DMA_FIFOMode = DMA_FIFOMode_Disable;
	DMAinit.DMA_FIFOThreshold = DMA_FIFOThreshold_HalfFull;

	DMA_Init( DMA2_Stream2,  &DMAinit);

	//enable DMA
	DMA_Cmd(DMA2_Stream2, ENABLE);

	//Configure DMA interrupt
	DMA_ITConfig(DMA2_Stream2, DMA_IT_TC, ENABLE);
	DMA_ITConfig(DMA2_Stream2, DMA_IT_HT | DMA_IT_TE | DMA_IT_FE | DMA_IT_DME, DISABLE);

	SPI_I2S_DMACmd(SPI1, SPI_I2S_DMAReq_Tx, ENABLE);

	while(!tx_complete){__WFI();}

	DMA_ITConfig(DMA2_Stream2, DMA_IT_TC, DISABLE);

	DMA_Cmd(DMA2_Stream2, DISABLE);
	while(DMA_GetCmdStatus(DMA2_Stream2) == ENABLE ){;}

	SPI_I2S_DMACmd(SPI1, SPI_I2S_DMAReq_Tx, DISABLE);

	tx_complete = 0;
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
